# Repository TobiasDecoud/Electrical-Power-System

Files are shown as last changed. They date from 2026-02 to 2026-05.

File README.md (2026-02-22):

# Electrical-Power-Subsystem

Necesitamos:
 
  Potencia Requerida: Estimar el consumo de energía promedio y pico de todos los subsistemas del satélite.
  
  Órbita del Satélite: Determinar los períodos de luz solar y eclipse para dimensionar los paneles solares y la capacidad de las baterías.
  
  Vida Útil: Seleccionar componentes que puedan soportar la duración de la misión y los ciclos de carga y descarga.

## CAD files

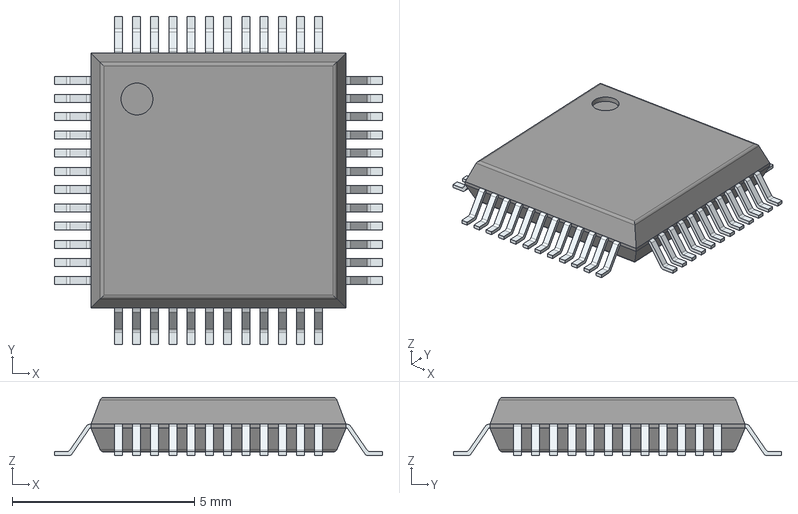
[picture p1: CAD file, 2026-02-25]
PCB/Footprints/LIB_STM32F103C8T6/STM32F103C8T6/3D/STM32F103C8T6.stp
9.00 x 9.00 x 1.60 mm
PinsArrayLR
PinsArrayTB

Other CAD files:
PCB/Footprints/LIB_STM32F103C8T6/STM32F103C8T6/Allegro/qfp50p900x900x160-48n.psm
PCB/Footprints/LIB_STM32F103C8T6/STM32F103C8T6/DEHDL/stm32f103c8t6/chips/chips.prt

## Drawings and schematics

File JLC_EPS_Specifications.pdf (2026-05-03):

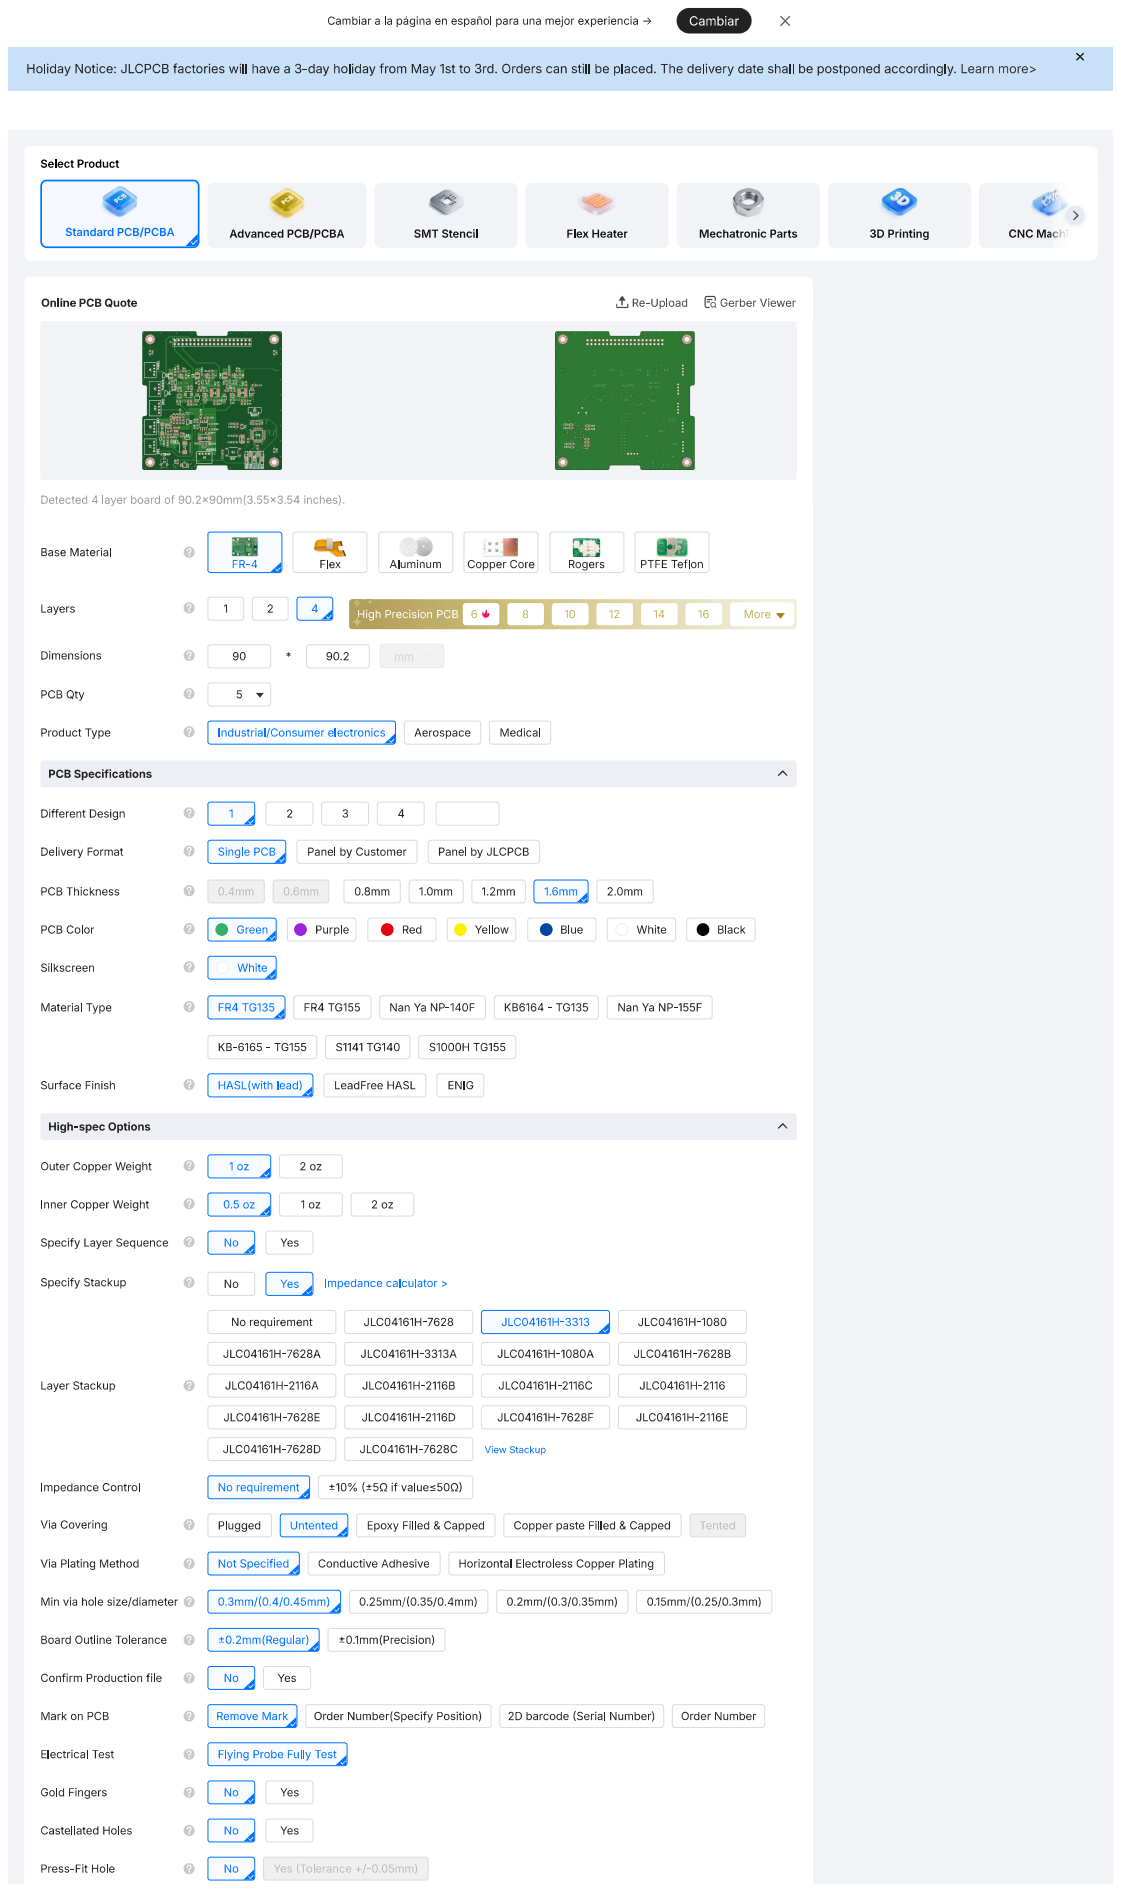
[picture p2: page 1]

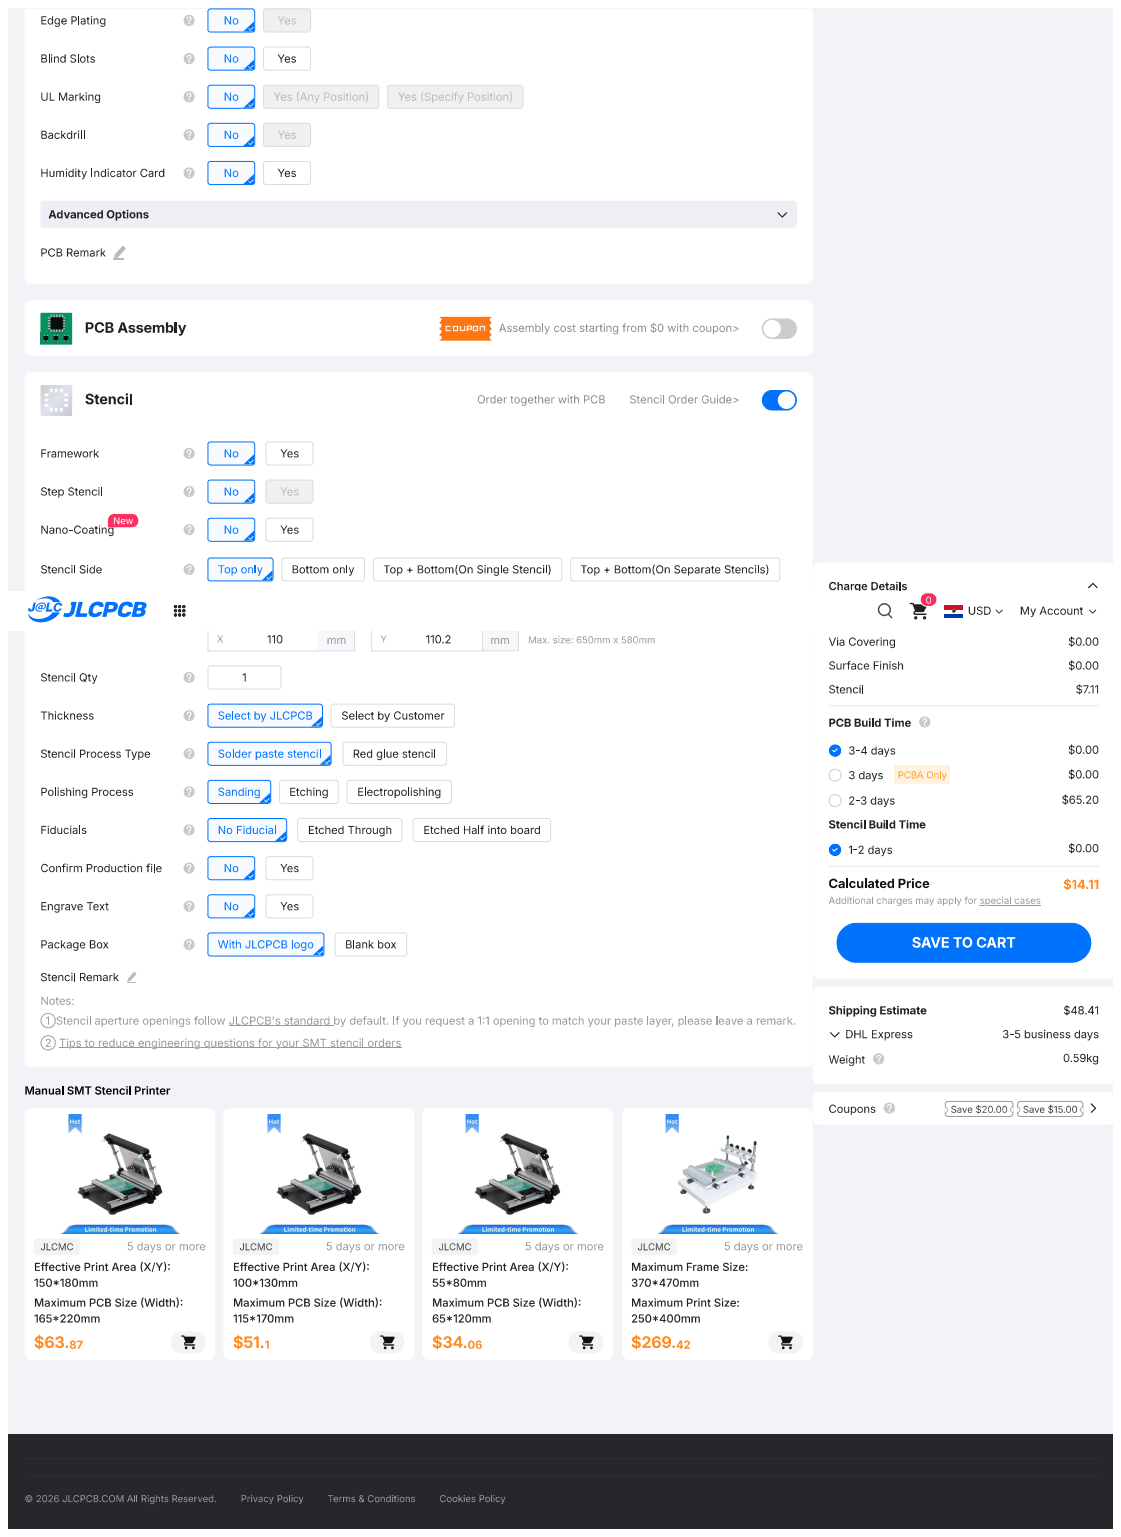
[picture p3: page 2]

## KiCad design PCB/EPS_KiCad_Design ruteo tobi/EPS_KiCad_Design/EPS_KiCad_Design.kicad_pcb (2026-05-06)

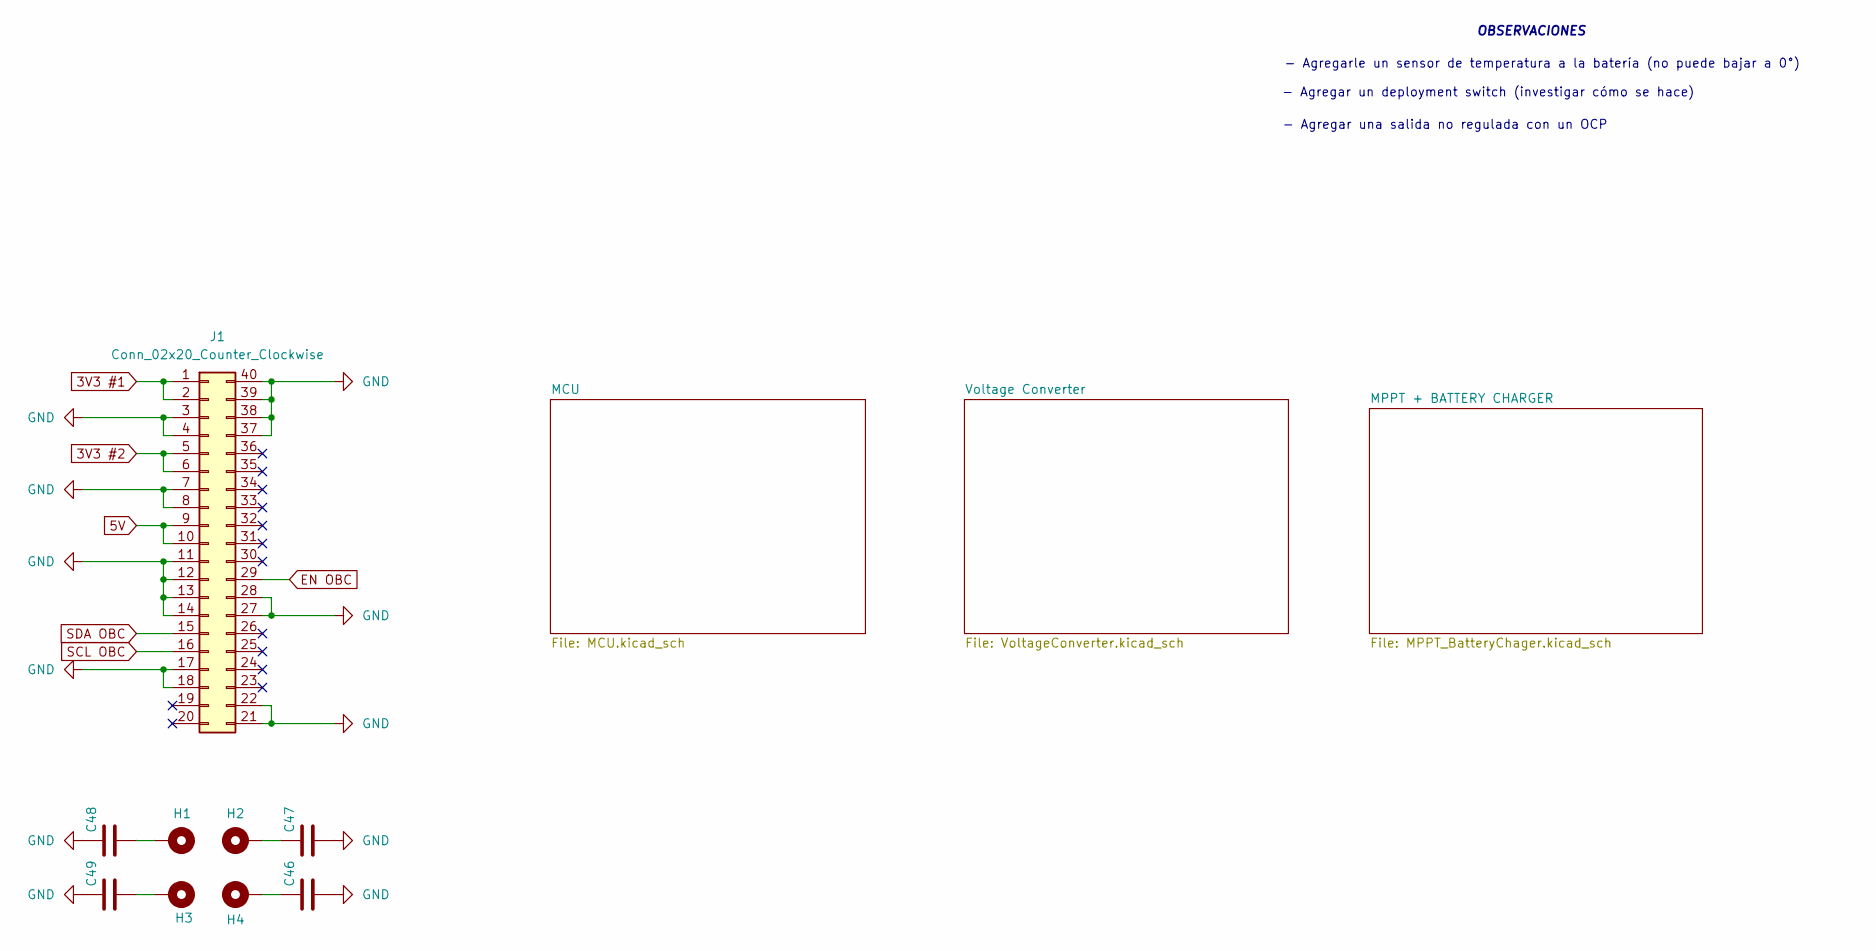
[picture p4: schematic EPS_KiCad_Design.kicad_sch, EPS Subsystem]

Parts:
C46, C47, C48, C49: 100nF; C_0805_2012Metric_Pad1.18x1.45mm_HandSolder
H1, H2, H3, H4: MountingHole_Pad; MountingHole_3.2mm_M3_Pad_Via
J1: Conn_02x20_Counter_Clockwise; PinSocket_2x20_P2.54mm_Vertical

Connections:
3V3 #1: J1.1, J1.2; also elsewhere on the board
3V3 #2: J1.5, J1.6; also elsewhere on the board
5V: J1.9, J1.10; also elsewhere on the board
EN OBC: J1.29; also elsewhere on the board
GND: C46.2, C47.2, C48.1, C49.1, J1.3, J1.4, J1.7, J1.8, J1.11, J1.12, J1.13, J1.14, J1.17, J1.18, J1.21, J1.22, J1.27, J1.28, J1.37, J1.38, J1.39, J1.40; also elsewhere on the board
unnamed: C46.1, H4.1
unnamed: C47.1, H2.1
unnamed: C48.2, H1.1
unnamed: C49.2, H3.1
SCL OBC: J1.16; also elsewhere on the board
SDA OBC: J1.15; also elsewhere on the board

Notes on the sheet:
OBSERVACIONES
- Agregar un deployment switch (investigar cómo se hace)
- Agregarle un sensor de temperatura a la batería (no puede bajar a 0°)
- Agregar una salida no regulada con un OCP

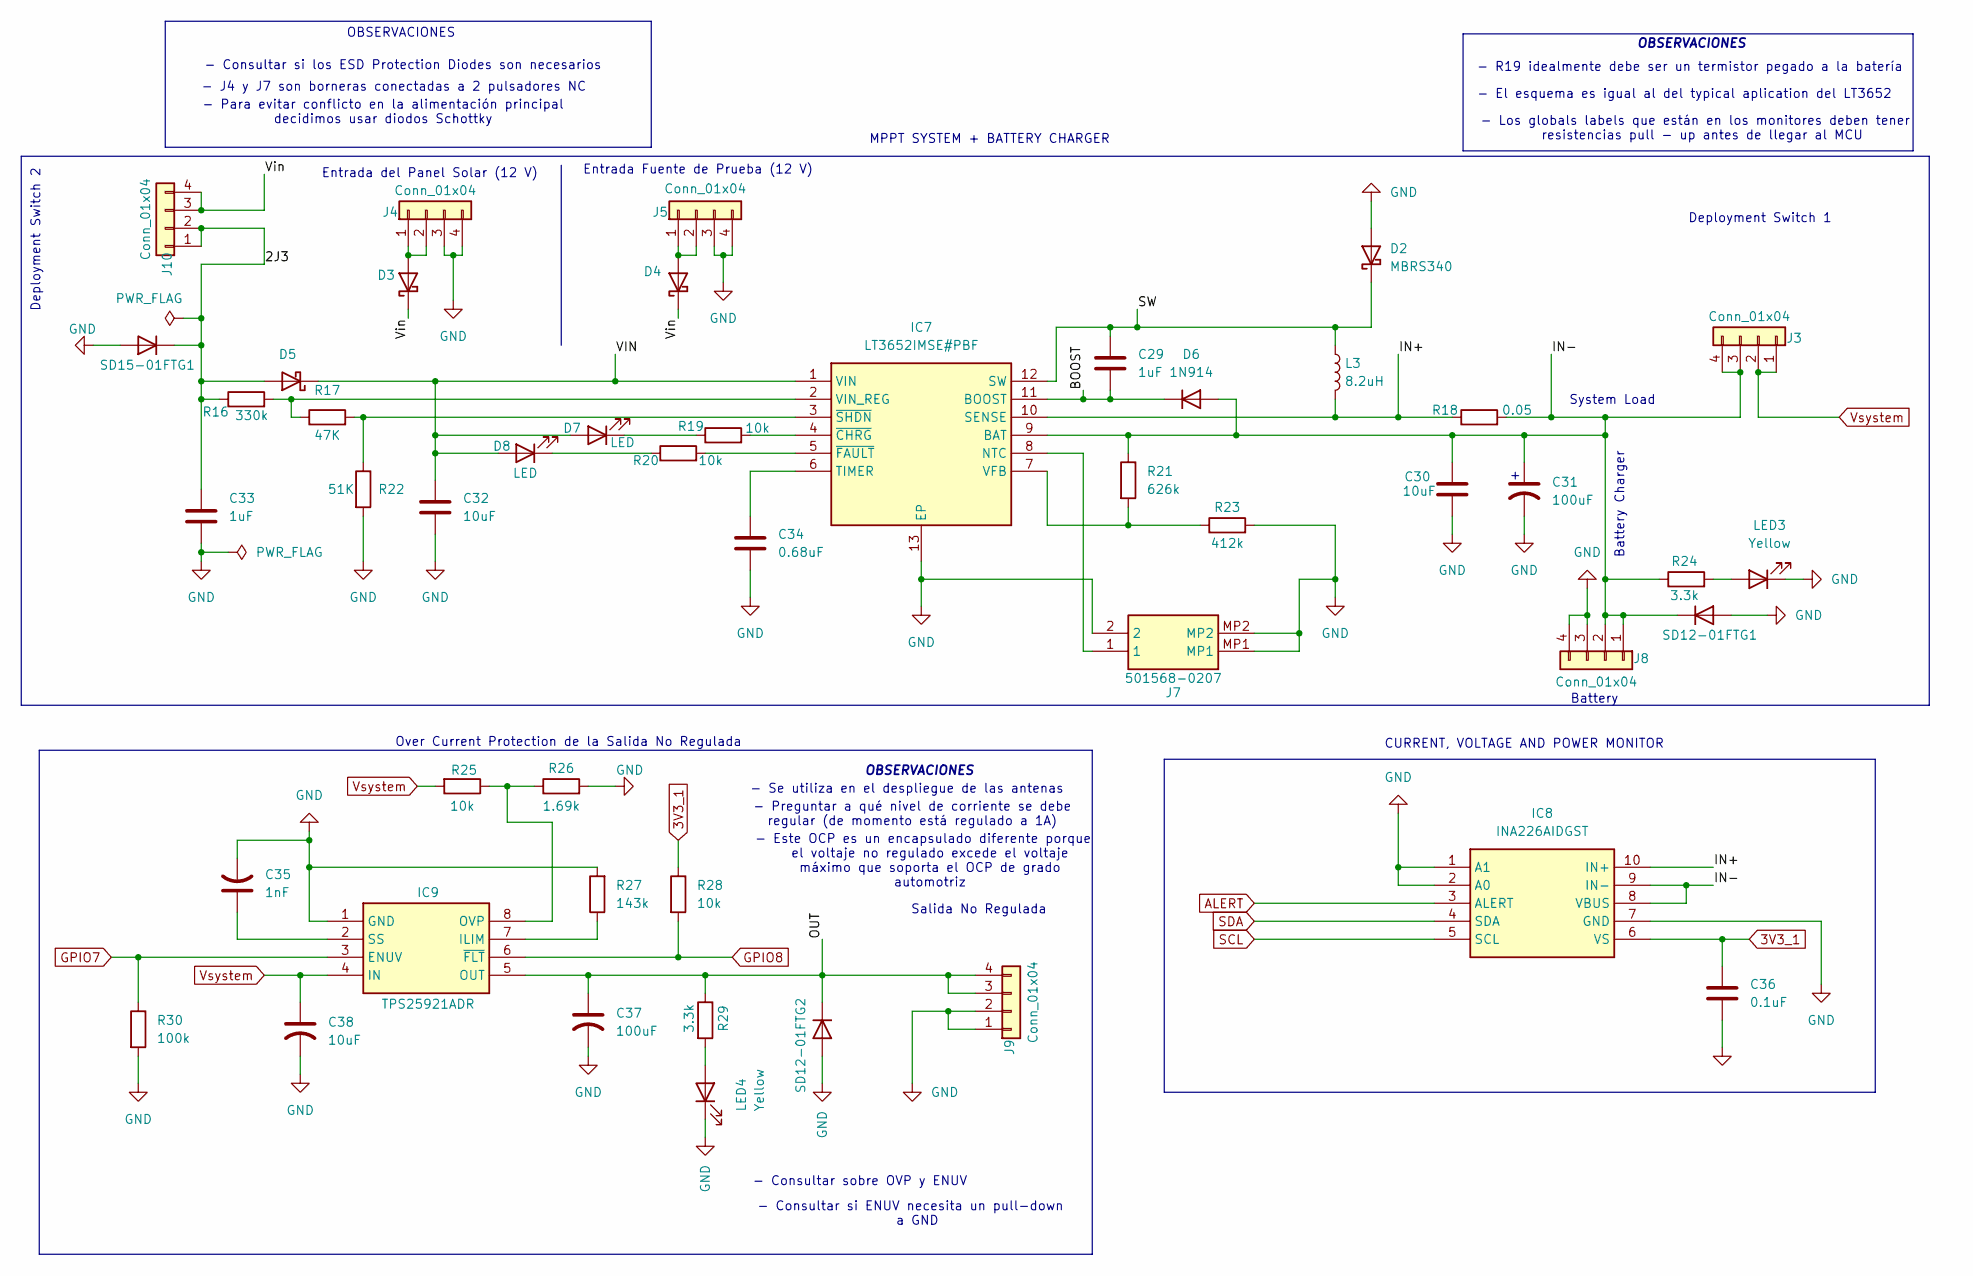
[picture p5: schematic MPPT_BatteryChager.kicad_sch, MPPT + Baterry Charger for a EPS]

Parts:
C29, C33: 1uF; C_0805_2012Metric_Pad1.18x1.45mm_HandSolder
C30, C32, C38: 10uF; C_0805_2012Metric_Pad1.18x1.45mm_HandSolder
C31, C37: 100uF; CAPPM7344X310N
C34: 0.68uF; C_0805_2012Metric_Pad1.18x1.45mm_HandSolder
C35: 1nF; C_0805_2012Metric_Pad1.18x1.45mm_HandSolder
C36: 0.1uF; C_0805_2012Metric_Pad1.18x1.45mm_HandSolder
D2, D3, D4, D5: MBRS340; SODFL3517X110N
D6: 1N914; SODFL4725X110N
D7, D8: LED; LED_0805_2012Metric_Pad1.15x1.40mm_HandSolder
IC7: LT3652IMSE#PBF; SOP65P490X110-13N; Mouser Part Number 584-LT3652IMSE#PBF
IC8: INA226AIDGST; SOP50P490X110-10N; Mouser Part Number 595-INA226AIDGST
IC9: TPS25921ADR; SOIC127P600X175-8N; Mouser Part Number 595-TPS25921ADR
J3, J4, J5, J8, J9, J10: Conn_01x04; 62000411722
J7: 501568-0207; 5015680207; Mouser Part Number 538-501568-0207
L3: 8.2uH; INDPM7168X300N
LED3, LED4: Yellow; LED_0805_2012Metric_Pad1.15x1.40mm_HandSolder
R16: 330k; R_0805_2012Metric_Pad1.20x1.40mm_HandSolder
R17: 47K; R_0805_2012Metric_Pad1.20x1.40mm_HandSolder
R18: 0.05; R_0805_2012Metric_Pad1.20x1.40mm_HandSolder
R19, R20, R25, R28: 10k; R_0805_2012Metric_Pad1.20x1.40mm_HandSolder
R21: 626k; R_0805_2012Metric_Pad1.20x1.40mm_HandSolder
R22: 51K; R_0805_2012Metric_Pad1.20x1.40mm_HandSolder
R23: 412k; R_0805_2012Metric_Pad1.20x1.40mm_HandSolder
R24, R29: 3.3k; R_0805_2012Metric_Pad1.20x1.40mm_HandSolder
R26: 1.69k; R_0805_2012Metric_Pad1.20x1.40mm_HandSolder
R27: 143k; R_0805_2012Metric_Pad1.20x1.40mm_HandSolder
R30: 100k; R_0805_2012Metric_Pad1.20x1.40mm_HandSolder
SD12-01FTG1, SD12-01FTG2: SOD2613X114N
SD15-01FTG1: D; SOD2613X114N

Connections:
3V3_1: C36.1, IC8.6 (VS), R28.1; also elsewhere on the board
/MPPT + BATTERY CHARGER/2J3: C33.1, D5.2 (A), J10.1, J10.2, R16.1, SD15-01FTG1.1 (K)
/MPPT + BATTERY CHARGER/BOOST: C29.2, D6.1 (K), IC7.11 (BOOST)
/MPPT + BATTERY CHARGER/IN+: IC7.10 (SENSE), IC8.10 (IN+), L3.2, R18.1
/MPPT + BATTERY CHARGER/IN-: C30.1, C31.1, D6.2 (A), IC7.9 (BAT), IC8.8 (VBUS), IC8.9 (IN-), J3.3, J3.4, J8.1, J8.2, R18.2, R21.1, R24.1, SD12-01FTG1.1 (K)
/MPPT + BATTERY CHARGER/OUT: C37.1, IC9.5 (OUT), J9.3, J9.4, R29.1, SD12-01FTG2.1 (K)
/MPPT + BATTERY CHARGER/SW: C29.1, D2.1 (K), IC7.12 (SW), L3.1
/MPPT + BATTERY CHARGER/VIN: C32.1, D5.1 (K), D7.2 (A), D8.2 (A), IC7.1 (VIN)
/MPPT + BATTERY CHARGER/Vin: D3.1 (K), D4.1 (K), J10.3, J10.4
ALERT: IC8.3 (ALERT); also elsewhere on the board
GND: C30.2, C31.2, C32.2, C33.2, C34.2, C35.2, C36.2, C37.2, C38.2, D2.2 (A), IC7.13 (EP), IC8.1 (A1), IC8.2 (A0), IC8.7 (GND), IC9.1 (GND), J4.3, J4.4, J5.3, J5.4, J7.2, J7.MP1, J7.MP2, J8.3, J8.4, J9.1, J9.2, LED3.1 (K), LED4.1 (K), R22.2, R23.2, R26.2, R27.2, R30.2, SD12-01FTG1.2 (A), SD12-01FTG2.2 (A), SD15-01FTG1.2 (A); also elsewhere on the board
GPIO7: IC9.3 (ENUV), R30.1; also elsewhere on the board
GPIO8: IC9.6 (~FLT), R28.2; also elsewhere on the board
unnamed: D3.2 (A), J4.1, J4.2
unnamed: D4.2 (A), J5.1, J5.2
unnamed: D7.1 (K), R19.1
unnamed: D8.1 (K), R20.1
unnamed: IC7.8 (NTC), J7.1
unnamed: C34.1, IC7.6 (TIMER)
unnamed: IC7.7 (VFB), R21.2, R23.1
unnamed: IC7.2 (VIN_REG), R16.2, R17.1
unnamed: IC7.4 (~CHRG), R19.2
unnamed: IC7.5 (~FAULT), R20.2
unnamed: IC7.3 (~SHDN), R17.2, R22.1
unnamed: IC9.7 (ILIM), R27.1
unnamed: IC9.8 (OVP), R25.1, R26.1
unnamed: C35.1, IC9.2 (SS)
unnamed: LED3.2 (A), R24.2
unnamed: LED4.2 (A), R29.2
SCL: IC8.5 (SCL); also elsewhere on the board
SDA: IC8.4 (SDA); also elsewhere on the board
Vsystem: C38.1, IC9.4 (IN), J3.1, J3.2, R25.2; also elsewhere on the board

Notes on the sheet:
CURRENT, VOLTAGE AND POWER MONITOR
- Se utiliza en el despliegue de las antenas
System Load
OBSERVACIONES
Entrada del Panel Solar (12 V)
- Los globals labels que están en los monitores deben tener resistencias pull - up antes de llegar al MCU
- Para evitar conflicto en la alimentación principal decidimos usar diodos Schottky
Battery Charger
- Este OCP es un encapsulado diferente porque el voltaje no regulado excede el voltaje máximo que soporta el OCP de grado automotriz
- El esquema es igual al del typical aplication del LT3652
Over Current Protection de la Salida No Regulada
- Consultar si ENUV necesita un pull-down a GND
Deployment Switch 1
Entrada Fuente de Prueba (12 V)
Deployment Switch 2
- R19 idealmente debe ser un termistor pegado a la batería
- J4 y J7 son borneras conectadas a 2 pulsadores NC
- Consultar si los ESD Protection Diodes son necesarios
- Consultar sobre OVP y ENUV
Salida No Regulada
- Preguntar a qué nivel de corriente se debe regular (de momento está regulado a 1A)
Battery
MPPT SYSTEM + BATTERY CHARGER

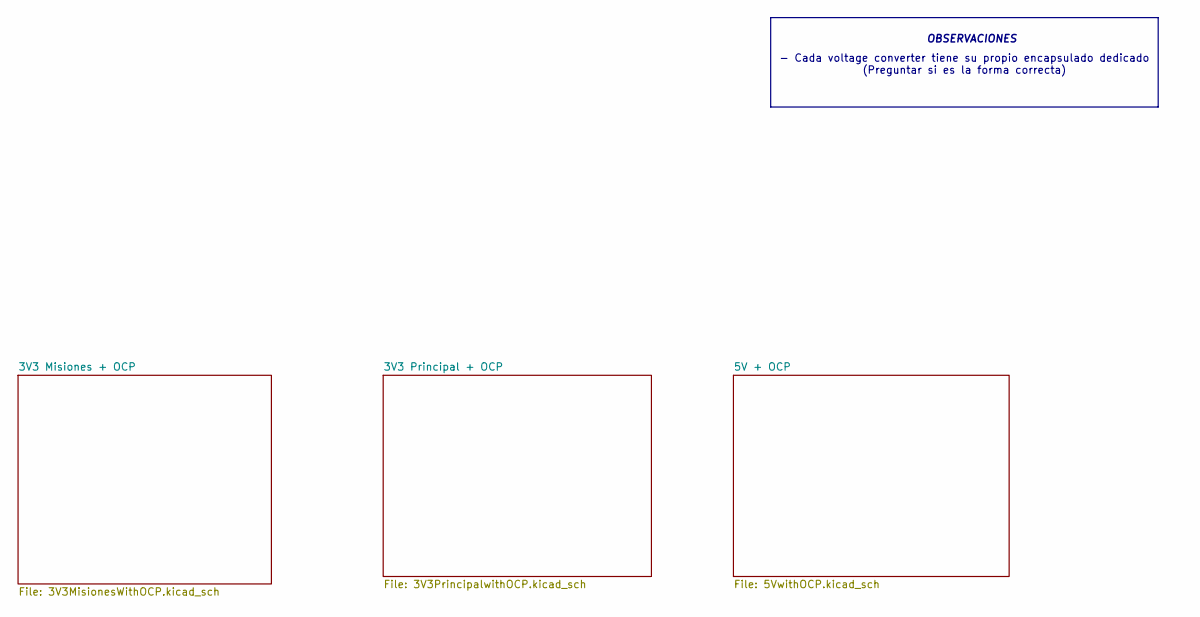
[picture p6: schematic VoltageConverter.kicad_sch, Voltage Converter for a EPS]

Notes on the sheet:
- Cada voltage converter tiene su propio encapsulado dedicado (Preguntar si es la forma correcta)
OBSERVACIONES

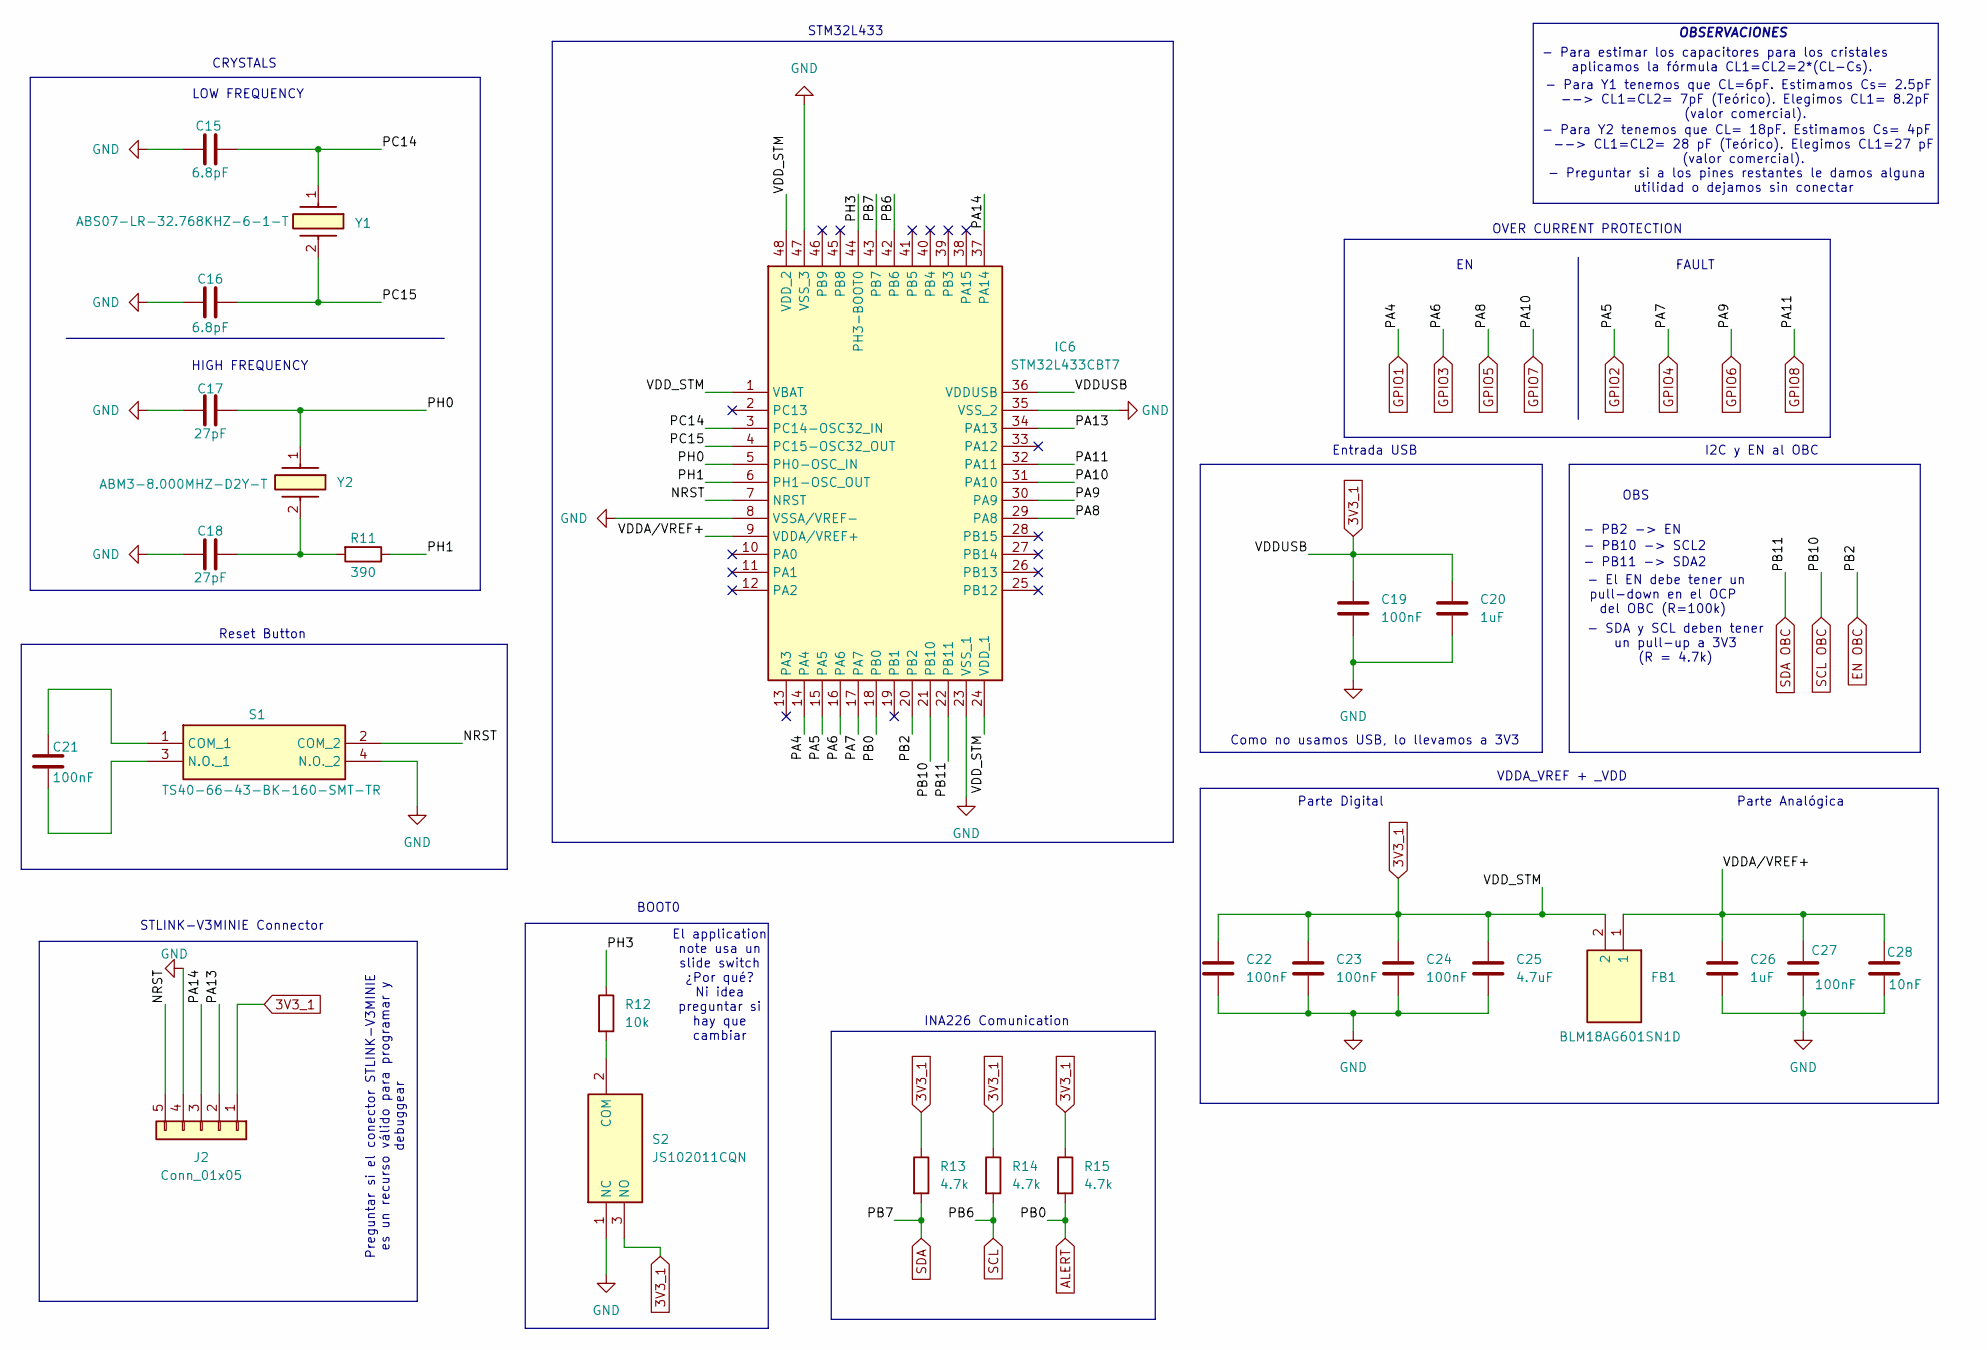
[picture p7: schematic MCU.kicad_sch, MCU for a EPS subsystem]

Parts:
C15, C16: 6.8pF; C_0805_2012Metric_Pad1.18x1.45mm_HandSolder
C17, C18: 27pF; C_0805_2012Metric_Pad1.18x1.45mm_HandSolder
C19, C21, C22, C23, C24, C27: 100nF; C_0805_2012Metric_Pad1.18x1.45mm_HandSolder
C20, C26: 1uF; C_0805_2012Metric_Pad1.18x1.45mm_HandSolder
C25: 4.7uF; C_0805_2012Metric_Pad1.18x1.45mm_HandSolder
C28: 10nF; C_0805_2012Metric_Pad1.18x1.45mm_HandSolder
FB1: BLM18AG601SN1D; BLM18SP221SN1B; Mouser Part Number 81-BLM11A601S
IC6: STM32L433CBT7; QFP50P900X900X160-48N; Mouser Part Number 511-STM32L433CBT7
J2: Conn_01x05; TSM10501LSV
R11: 390; R_0805_2012Metric_Pad1.20x1.40mm_HandSolder
R12: 10k; R_0805_2012Metric_Pad1.20x1.40mm_HandSolder
R13, R14, R15: 4.7k; R_0805_2012Metric_Pad1.20x1.40mm_HandSolder
S1: TS40-66-43-BK-160-SMT-TR; TS406643BK160SMTTR; Manufacturer_Part_Number TS40-66-43-BK-160-SMT-TR
S2: JS102011CQN; Mouser Part Number 611-JS102011CQN
Y1: ABS07-LR-32.768KHZ-6-1-T; ABS07LR32768kHz61T; Mouser Part Number 815-ABS07LR32.76-61T
Y2: ABM3-8.000MHZ-D2Y-T; ABM3; Mouser Part Number 815-ABM3-8-D2Y-T

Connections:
3V3_1: C19.1, C20.1, C22.1, C23.1, C24.1, C25.1, FB1.2, IC6.1 (VBAT), IC6.24 (VDD_1), IC6.36 (VDDUSB), IC6.48 (VDD_2), J2.1, R13.1, R14.1, R15.1, S2.3 (NO); also elsewhere on the board
/MCU/NRST: IC6.7 (NRST), J2.5, S1.2 (COM_2)
/MCU/PA13: IC6.34 (PA13), J2.2
/MCU/PA14: IC6.37 (PA14), J2.3
/MCU/PC14: C15.2, IC6.3 (PC14-OSC32_IN), Y1.1
/MCU/PC15: C16.2, IC6.4 (PC15-OSC32_OUT), Y1.2
/MCU/PH0: C17.1, IC6.5 (PH0-OSC_IN), Y2.1
/MCU/PH1: IC6.6 (PH1-OSC_OUT), R11.1
/MCU/PH3: IC6.44 (PH3-BOOT0), R12.1
/MCU/VDDA/VREF+: C26.1, C27.1, C28.1, FB1.1, IC6.9 (VDDA/VREF+)
ALERT: IC6.18 (PB0), R15.2; also elsewhere on the board
EN OBC: IC6.20 (PB2); also elsewhere on the board
GND: C15.1, C16.1, C17.2, C18.2, C19.2, C20.2, C22.2, C23.2, C24.2, C25.2, C26.2, C27.2, C28.2, IC6.8 (VSSA/VREF-), IC6.23 (VSS_1), IC6.35 (VSS_2), IC6.47 (VSS_3), J2.4, S1.4 (N.O._2), S2.1 (NC); also elsewhere on the board
GPIO1: IC6.14 (PA4); also elsewhere on the board
GPIO2: IC6.15 (PA5); also elsewhere on the board
GPIO3: IC6.16 (PA6); also elsewhere on the board
GPIO4: IC6.17 (PA7); also elsewhere on the board
GPIO5: IC6.29 (PA8); also elsewhere on the board
GPIO6: IC6.30 (PA9); also elsewhere on the board
GPIO7: IC6.31 (PA10); also elsewhere on the board
GPIO8: IC6.32 (PA11); also elsewhere on the board
unnamed: C18.1, R11.2, Y2.2
unnamed: C21.1, S1.1 (COM_1)
unnamed: C21.2, S1.3 (N.O._1)
unnamed: R12.2, S2.2 (COM)
SCL: IC6.42 (PB6), R14.2; also elsewhere on the board
SCL OBC: IC6.21 (PB10); also elsewhere on the board
SDA: IC6.43 (PB7), R13.2; also elsewhere on the board
SDA OBC: IC6.22 (PB11); also elsewhere on the board

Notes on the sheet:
BOOT0
- SDA y SCL deben tener un pull-up a 3V3 (R = 4.7k)
OBSERVACIONES
LOW FREQUENCY
- PB2 -> EN
- PB10 -> SCL2
OVER CURRENT PROTECTION
- El EN debe tener un pull-down en el OCP del OBC (R=100k)
Entrada USB
- Para Y2 tenemos que CL= 18pF. Estimamos Cs= 4pF --> CL1=CL2= 28 pF (Teórico). Elegimos CL1=27 pF (valor comercial).
- PB11 -> SDA2
INA226 Comunication
- Preguntar si a los pines restantes le damos alguna utilidad o dejamos sin conectar
Parte Digital
Preguntar si el conector STLINK-V3MINIE es un recurso válido para programar y debuggear
STLINK-V3MINIE Connector
OBS
Reset Button
I2C y EN al OBC
Parte Analógica
FAULT
Como no usamos USB, lo llevamos a 3V3
VDDA_VREF + _VDD
- Para Y1 tenemos que CL=6pF. Estimamos Cs= 2.5pF --> CL1=CL2= 7pF (Teórico). Elegimos CL1= 8.2pF (valor comercial).
El application note usa un slide switch ¿Por qué? Ni idea preguntar si hay que cambiar
CRYSTALS
HIGH FREQUENCY
STM32L433
- Para estimar los capacitores para los cristales aplicamos la fórmula CL1=CL2=2*(CL-Cs).

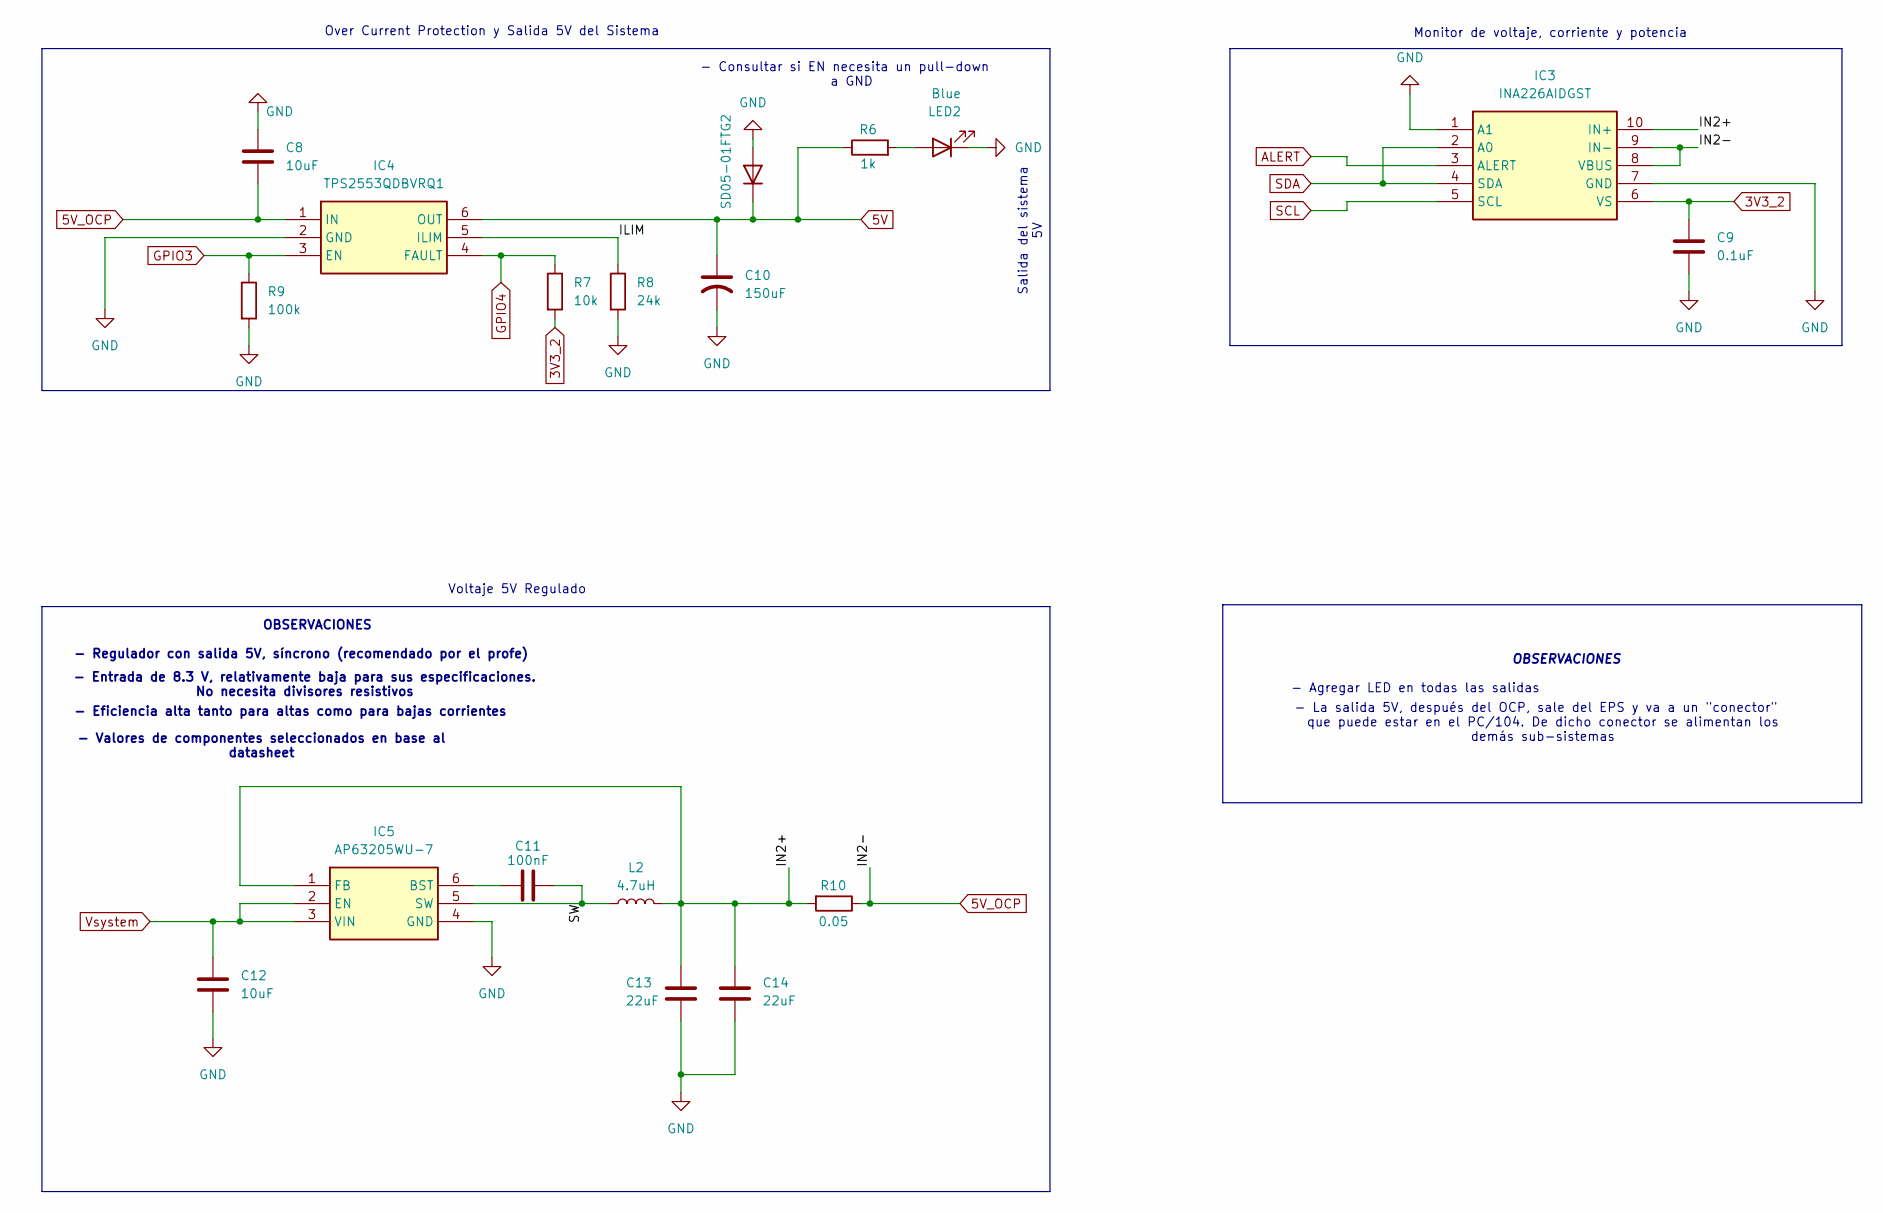
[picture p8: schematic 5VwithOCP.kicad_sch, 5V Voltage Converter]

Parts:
C8, C12: 10uF; C_0805_2012Metric_Pad1.18x1.45mm_HandSolder
C9: 0.1uF; C_0805_2012Metric_Pad1.18x1.45mm_HandSolder
C10: 150uF; CAPPM3528X210N
C11: 100nF; C_0805_2012Metric_Pad1.18x1.45mm_HandSolder
C13, C14: 22uF; C_0805_2012Metric_Pad1.18x1.45mm_HandSolder
IC3: INA226AIDGST; SOP50P490X110-10N; Mouser Part Number 595-INA226AIDGST
IC4: TPS2553QDBVRQ1; SOT95P280X145-6N; Mouser Part Number 595-TPS2553QDBVRQ1
IC5: AP63205WU-7; AP63205WU7; Mouser Part Number 621-AP63205WU-7
L2: 4.7uH; INDPM4441X200N
LED2: Blue; LED_0805_2012Metric_Pad1.15x1.40mm_HandSolder
R6: 1k; R_0805_2012Metric_Pad1.20x1.40mm_HandSolder
R7: 10k; R_0805_2012Metric_Pad1.20x1.40mm_HandSolder
R8: 24k; R_0805_2012Metric_Pad1.20x1.40mm_HandSolder
R9: 100k; R_0805_2012Metric_Pad1.20x1.40mm_HandSolder
R10: 0.05; R_0805_2012Metric_Pad1.20x1.40mm_HandSolder
SD05-01FTG2: D; SODFL3718X140N

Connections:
3V3_2: C9.1, IC3.6 (VS), R7.2; also elsewhere on the board
5V: C10.1, IC4.6 (OUT), R6.1, SD05-01FTG2.1 (K); also elsewhere on the board
5V_OCP: C8.2, IC3.8 (VBUS), IC3.9 (IN-), IC4.1 (IN), R10.1
/Voltage Converter/5V + OCP/ILIM: IC4.5 (ILIM), R8.1
/Voltage Converter/5V + OCP/IN2+: C13.1, C14.1, IC3.10 (IN+), IC5.1 (FB), L2.2, R10.2
/Voltage Converter/5V + OCP/SW: C11.2, IC5.5 (SW), L2.1
ALERT: IC3.3 (ALERT); also elsewhere on the board
GND: C8.1, C9.2, C10.2, C12.2, C13.2, C14.2, IC3.1 (A1), IC3.7 (GND), IC4.2 (GND), IC5.4 (GND), LED2.1 (K), R8.2, R9.2, SD05-01FTG2.2 (A); also elsewhere on the board
GPIO3: IC4.3 (EN), R9.1; also elsewhere on the board
GPIO4: IC4.4 (FAULT), R7.1; also elsewhere on the board
unnamed: C11.1, IC5.6 (BST)
unnamed: LED2.2 (A), R6.2
SCL: IC3.5 (SCL); also elsewhere on the board
SDA: IC3.2 (A0), IC3.4 (SDA); also elsewhere on the board
Vsystem: C12.1, IC5.2 (EN), IC5.3 (VIN); also elsewhere on the board

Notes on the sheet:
- Consultar si EN necesita un pull-down a GND
Voltaje 5V Regulado
OBSERVACIONES
- Eficiencia alta tanto para altas como para bajas corrientes
- Agregar LED en todas las salidas
- Entrada de 8.3 V, relativamente baja para sus especificaciones. No necesita divisores resistivos
Salida del sistema 5V
- La salida 5V, después del OCP, sale del EPS y va a un "conector" que puede estar en el PC/104. De dicho conector se alimentan los demás sub-sistemas
- Valores de componentes seleccionados en base al datasheet
Over Current Protection y Salida 5V del Sistema
Monitor de voltaje, corriente y potencia
- Regulador con salida 5V, síncrono (recomendado por el profe)

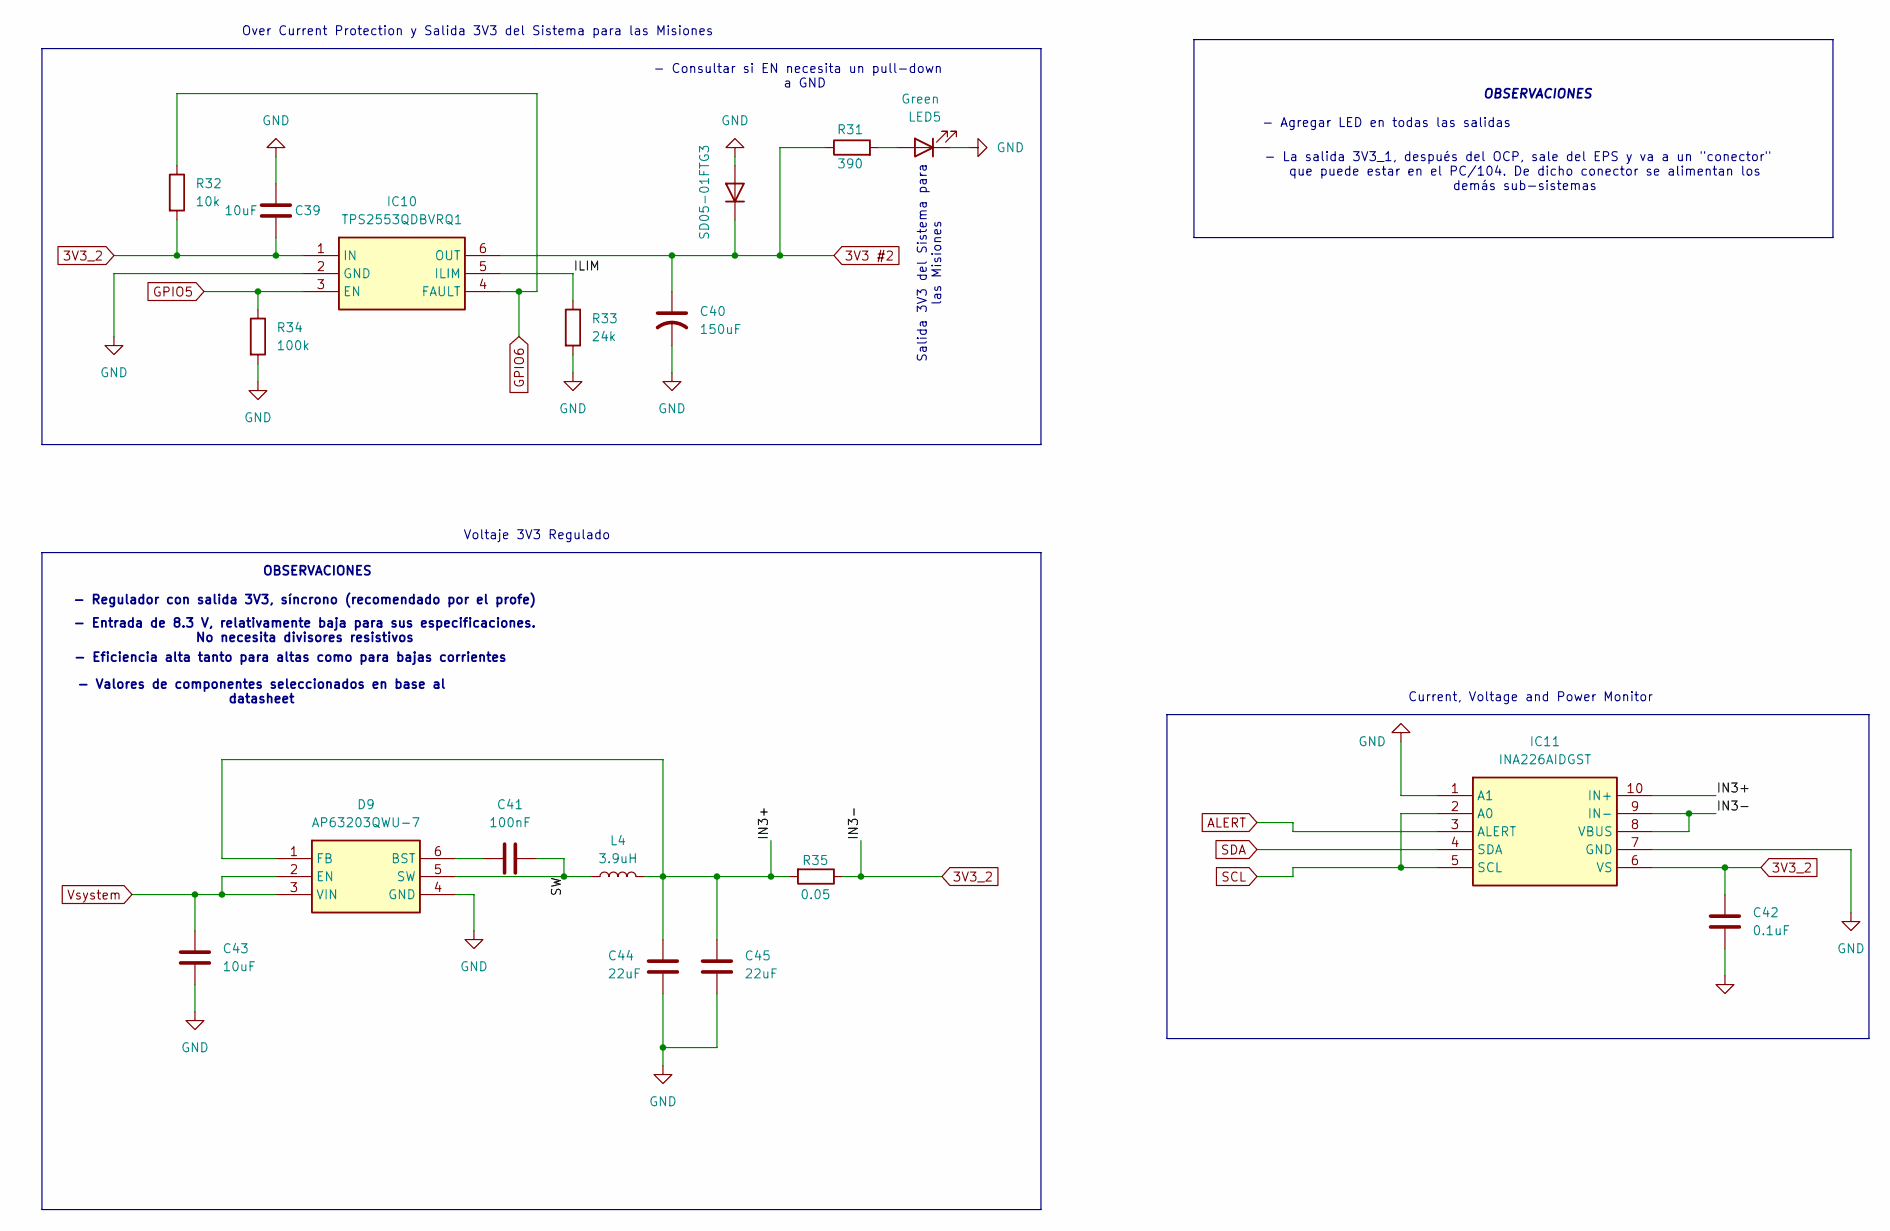
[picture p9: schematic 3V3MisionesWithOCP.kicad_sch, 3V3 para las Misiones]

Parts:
C39, C43: 10uF; C_0805_2012Metric_Pad1.18x1.45mm_HandSolder
C40: 150uF; CAPPM3528X210N
C41: 100nF; C_0805_2012Metric_Pad1.18x1.45mm_HandSolder
C42: 0.1uF; C_0805_2012Metric_Pad1.18x1.45mm_HandSolder
C44, C45: 22uF; C_0805_2012Metric_Pad1.18x1.45mm_HandSolder
D9: AP63203QWU-7; SOT95P280X100-6N; Mouser Part Number 621-AP63203QWU-7
IC10: TPS2553QDBVRQ1; SOT95P280X145-6N; Mouser Part Number 595-TPS2553QDBVRQ1
IC11: INA226AIDGST; SOP50P490X110-10N; Mouser Part Number 595-INA226AIDGST
L4: 3.9uH; ASPI0628150MT1
LED5: Green; LED_0805_2012Metric_Pad1.15x1.40mm_HandSolder
R31: 390; R_0805_2012Metric_Pad1.20x1.40mm_HandSolder
R32: 10k; R_0805_2012Metric_Pad1.20x1.40mm_HandSolder
R33: 24k; R_0805_2012Metric_Pad1.20x1.40mm_HandSolder
R34: 100k; R_0805_2012Metric_Pad1.20x1.40mm_HandSolder
R35: 0.05; R_0805_2012Metric_Pad1.20x1.40mm_HandSolder
SD05-01FTG3: D; SOD2613X114N

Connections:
3V3 #2: C40.1, IC10.6 (OUT), R31.1, SD05-01FTG3.1 (K); also elsewhere on the board
3V3_2: C39.1, C42.1, IC10.1 (IN), IC11.6 (VS), IC11.8 (VBUS), IC11.9 (IN-), R32.2, R35.1; also elsewhere on the board
/Voltage Converter/3V3 Misiones + OCP/ILIM: IC10.5 (ILIM), R33.1
/Voltage Converter/3V3 Misiones + OCP/IN3+: C44.1, C45.1, D9.1 (FB), IC11.10 (IN+), L4.2, R35.2
/Voltage Converter/3V3 Misiones + OCP/SW: C41.2, D9.5 (SW), L4.1
ALERT: IC11.3 (ALERT); also elsewhere on the board
GND: C39.2, C40.2, C42.2, C43.2, C44.2, C45.2, D9.4 (GND), IC10.2 (GND), IC11.1 (A1), IC11.7 (GND), LED5.1 (K), R33.2, R34.2, SD05-01FTG3.2 (A); also elsewhere on the board
GPIO5: IC10.3 (EN), R34.1; also elsewhere on the board
GPIO6: IC10.4 (FAULT), R32.1; also elsewhere on the board
unnamed: C41.1, D9.6 (BST)
unnamed: LED5.2 (A), R31.2
SCL: IC11.2 (A0), IC11.5 (SCL); also elsewhere on the board
SDA: IC11.4 (SDA); also elsewhere on the board
Vsystem: C43.1, D9.2 (EN), D9.3 (VIN); also elsewhere on the board

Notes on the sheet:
OBSERVACIONES
- Eficiencia alta tanto para altas como para bajas corrientes
- Entrada de 8.3 V, relativamente baja para sus especificaciones. No necesita divisores resistivos
Voltaje 3V3 Regulado
- Regulador con salida 3V3, síncrono (recomendado por el profe)
- Agregar LED en todas las salidas
Current, Voltage and Power Monitor
- Valores de componentes seleccionados en base al datasheet
Salida 3V3 del Sistema para las Misiones
- Consultar si EN necesita un pull-down a GND
Over Current Protection y Salida 3V3 del Sistema para las Misiones
- La salida 3V3_1, después del OCP, sale del EPS y va a un "conector" que puede estar en el PC/104. De dicho conector se alimentan los demás sub-sistemas

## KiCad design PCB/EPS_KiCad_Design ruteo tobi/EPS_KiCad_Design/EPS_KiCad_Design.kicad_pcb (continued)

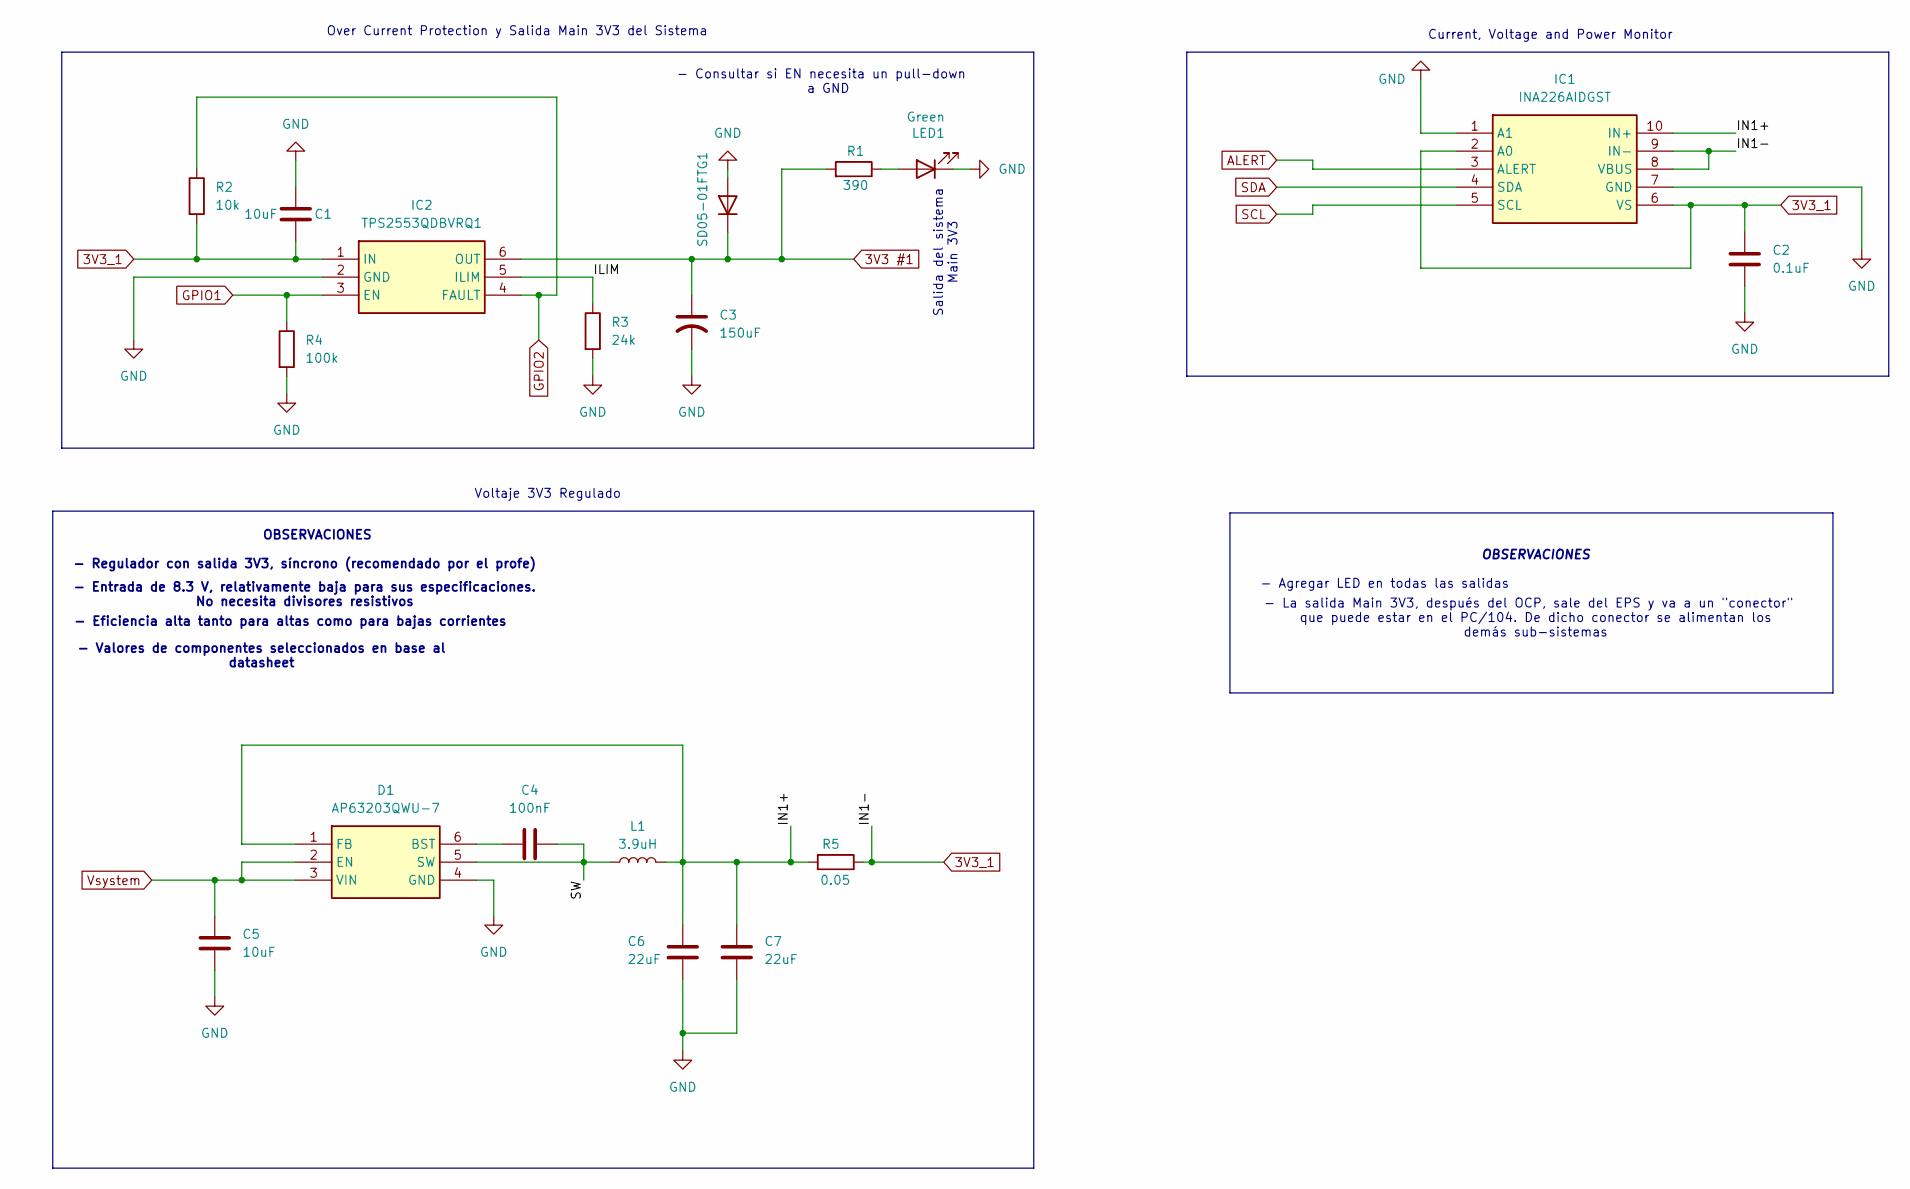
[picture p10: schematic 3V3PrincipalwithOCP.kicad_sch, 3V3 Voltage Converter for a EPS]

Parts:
C1, C5: 10uF; C_0805_2012Metric_Pad1.18x1.45mm_HandSolder
C2: 0.1uF; C_0805_2012Metric_Pad1.18x1.45mm_HandSolder
C3: 150uF; CAPPM3528X210N
C4: 100nF; C_0805_2012Metric_Pad1.18x1.45mm_HandSolder
C6, C7: 22uF; C_0805_2012Metric_Pad1.18x1.45mm_HandSolder
D1: AP63203QWU-7; SOT95P280X100-6N; Mouser Part Number 621-AP63203QWU-7
IC1: INA226AIDGST; SOP50P490X110-10N; Mouser Part Number 595-INA226AIDGST
IC2: TPS2553QDBVRQ1; SOT95P280X145-6N; Mouser Part Number 595-TPS2553QDBVRQ1
L1: 3.9uH; ASPI0628150MT1
LED1: Green; LED_0805_2012Metric_Pad1.15x1.40mm_HandSolder
R1: 390; R_0805_2012Metric_Pad1.20x1.40mm_HandSolder
R2: 10k; R_0805_2012Metric_Pad1.20x1.40mm_HandSolder
R3: 24k; R_0805_2012Metric_Pad1.20x1.40mm_HandSolder
R4: 100k; R_0805_2012Metric_Pad1.20x1.40mm_HandSolder
R5: 0.05; R_0805_2012Metric_Pad1.20x1.40mm_HandSolder
SD05-01FTG1: D; SOD2613X114N

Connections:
3V3 #1: C3.1, IC2.6 (OUT), R1.2, SD05-01FTG1.1 (K); also elsewhere on the board
3V3_1: C1.1, C2.1, IC1.2 (A0), IC1.6 (VS), IC1.8 (VBUS), IC1.9 (IN-), IC2.1 (IN), R2.2, R5.1; also elsewhere on the board
/Voltage Converter/3V3 Principal + OCP/ILIM: IC2.5 (ILIM), R3.1
/Voltage Converter/3V3 Principal + OCP/IN1+: C6.1, C7.1, D1.1 (FB), IC1.10 (IN+), L1.2, R5.2
/Voltage Converter/3V3 Principal + OCP/SW: C4.2, D1.5 (SW), L1.1
ALERT: IC1.3 (ALERT); also elsewhere on the board
GND: C1.2, C2.2, C3.2, C5.2, C6.2, C7.2, D1.4 (GND), IC1.1 (A1), IC1.7 (GND), IC2.2 (GND), LED1.1 (K), R3.2, R4.2, SD05-01FTG1.2 (A); also elsewhere on the board
GPIO1: IC2.3 (EN), R4.1; also elsewhere on the board
GPIO2: IC2.4 (FAULT), R2.1; also elsewhere on the board
unnamed: C4.1, D1.6 (BST)
unnamed: LED1.2 (A), R1.1
SCL: IC1.5 (SCL); also elsewhere on the board
SDA: IC1.4 (SDA); also elsewhere on the board
Vsystem: C5.1, D1.2 (EN), D1.3 (VIN); also elsewhere on the board

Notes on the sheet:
- Consultar si EN necesita un pull-down a GND
Voltaje 3V3 Regulado
Current, Voltage and Power Monitor
- Entrada de 8.3 V, relativamente baja para sus especificaciones. No necesita divisores resistivos
- Regulador con salida 3V3, síncrono (recomendado por el profe)
- Eficiencia alta tanto para altas como para bajas corrientes
OBSERVACIONES
- Valores de componentes seleccionados en base al datasheet
Salida del sistema Main 3V3
Over Current Protection y Salida Main 3V3 del Sistema
- Agregar LED en todas las salidas
- La salida Main 3V3, después del OCP, sale del EPS y va a un "conector" que puede estar en el PC/104. De dicho conector se alimentan los demás sub-sistemas

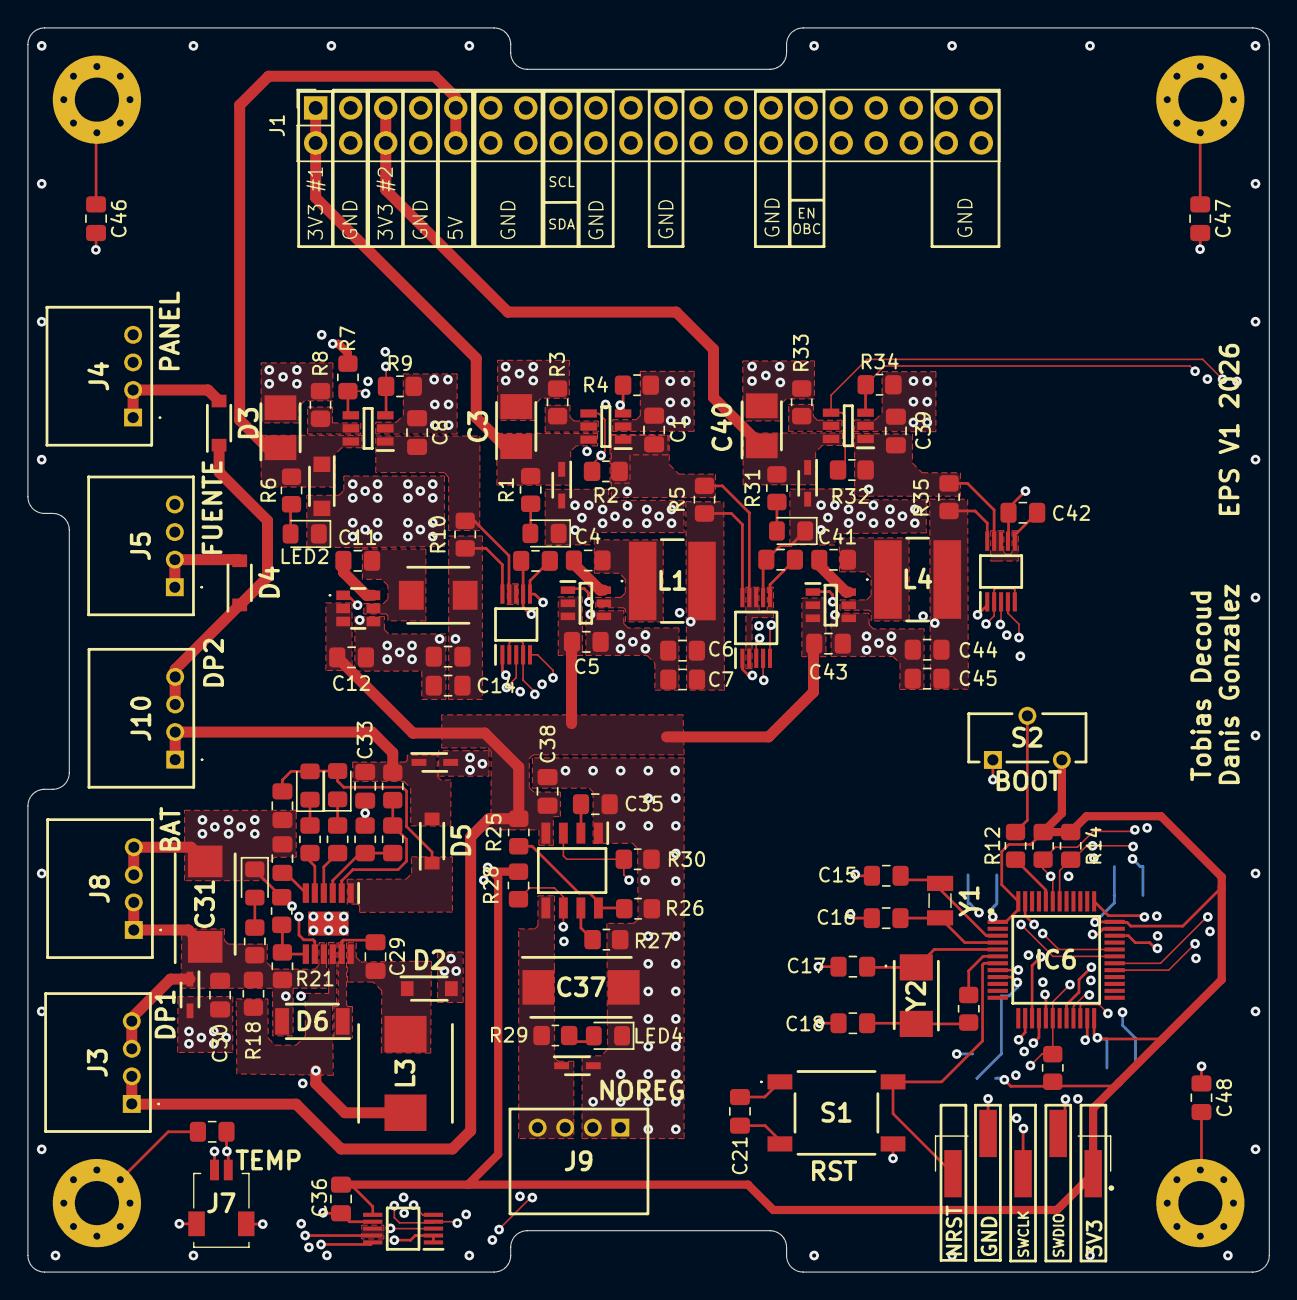
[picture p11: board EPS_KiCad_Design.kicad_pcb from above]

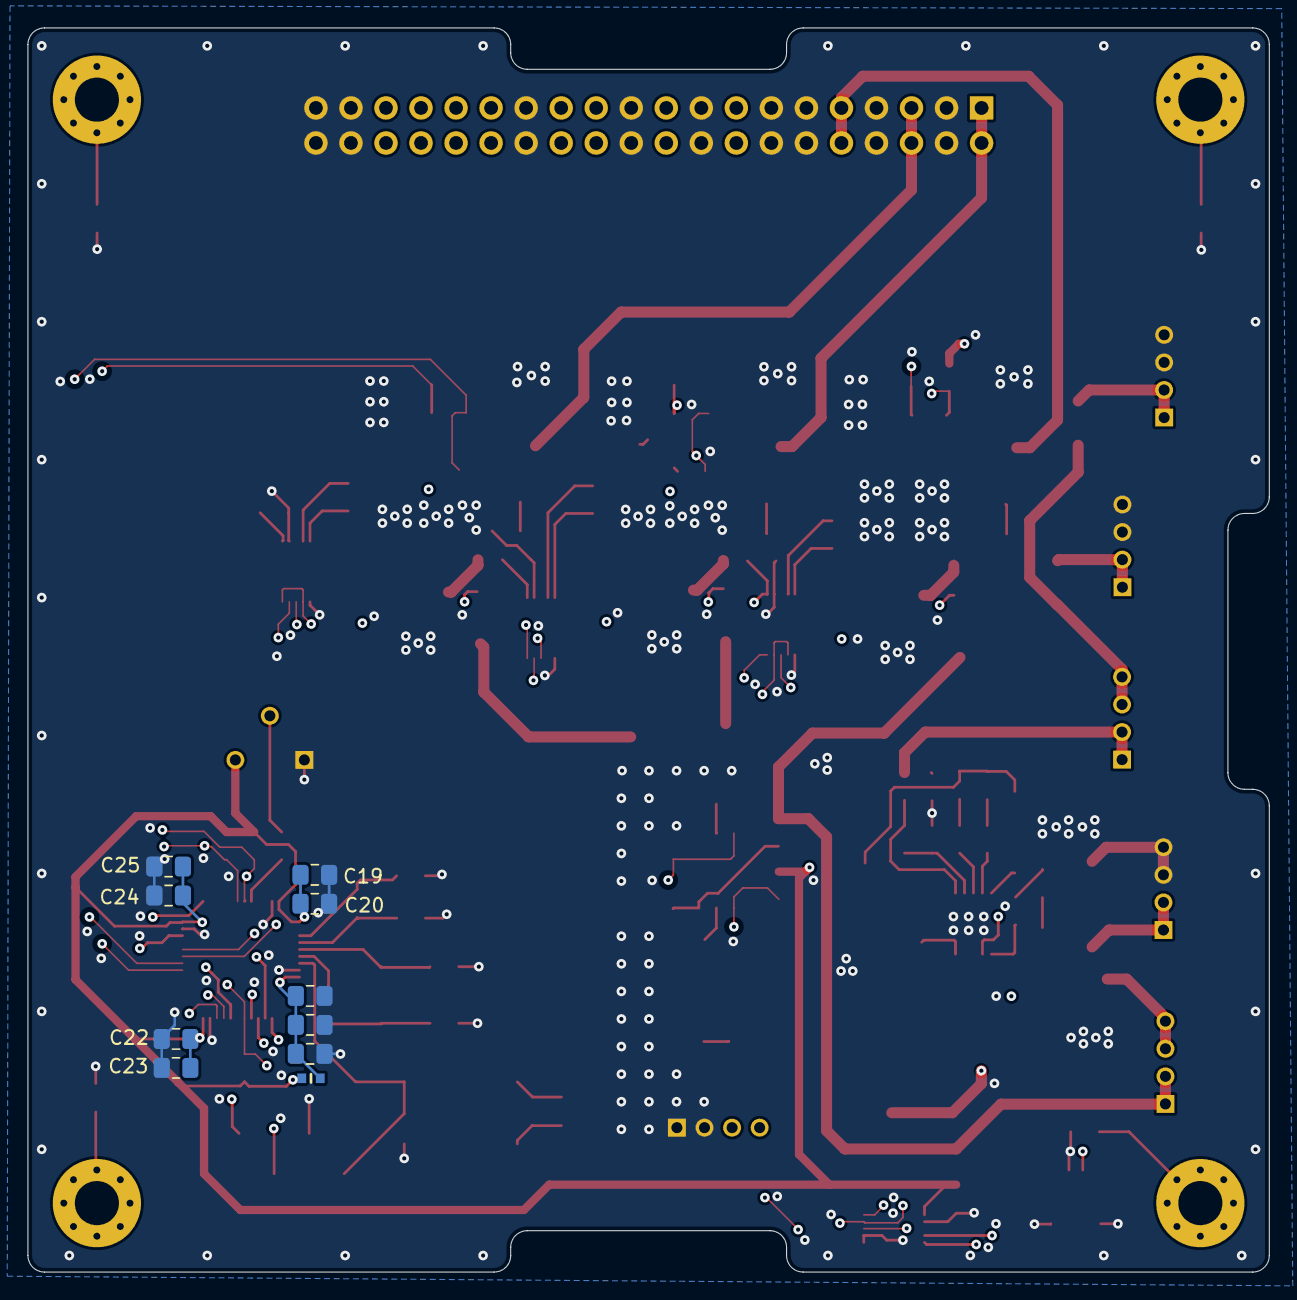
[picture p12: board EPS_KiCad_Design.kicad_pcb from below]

Board: 4 copper layers, 90.0 x 90.2 mm, 137 parts (10 on the bottom side), 78 nets.

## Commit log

2026-02-22 Actualizacion de README
2026-02-25 Inicio PCB
    [EDI2CAP.CFG, PCB_EPS.kicad_pcb, PCB_EPS.kicad_sch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]
2026-03-03 actualizacion pcb¨
2026-03-09 Main PCB - EPS
    [12V.kicad_sch, 3V3.kicad_sch, 5V.kicad_sch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]
2026-03-29 Cambio en el diagrama
2026-03-29 Cambie ubicacion de baterry en el diagrama
2026-04-15 Actualizacion del PCB en Kicad
    [12V.kicad_sch, 3V3.kicad_sch, 3V3MisionesWithOCP.kicad_sch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]
2026-04-20 cargue pcb
    [12V.kicad_sch, 3V3.kicad_sch, 3V3MisionesWithOCP.kicad_sch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]
2026-04-27 pcb tobi
    [3V3MisionesWithOCP.kicad_sch, 5VwithOCP.kicad_sch, EPS_KiCad_Design.kicad_pcb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]
2026-04-27 Ruteo parcial de MCU
    [EPS_KiCad_Design.kicad_pcb]
2026-04-28 Agregue cosas al ruteo MCU
    [EPS_KiCad_Design.kicad_pcb]
2026-04-28 Correcciones MCU ruteo
    [EPS_KiCad_Design.kicad_pcb]
2026-04-28 RUTEO MCU
    [EPS_KiCad_Design.kicad_pcb]
2026-04-28 Correccion de STP de los cristales
    [EPS_KiCad_Design.kicad_pcb]
2026-04-28 Cambios menores
    [EPS_KiCad_Design.kicad_pcb]
2026-04-29 Actualizacion del PCB
    [3V3MisionesWithOCP.kicad_sch, 3V3PrincipalwithOCP.kicad_sch, EPS_KiCad_Design.kicad_pcb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]
2026-04-30 Cambio de conector
    Conector header de 5 posiciones
    [MCU.kicad_sch]
2026-05-02 Estapadines agregados en el diseño
    [EPS_KiCad_Design.kicad_pcb]
2026-05-02 cambios en el ruteo
    [EPS_KiCad_Design.kicad_pcb, EPS_KiCad_Design.kicad_sch, MCU.kicad_sch]
2026-05-03 Cambios pcb
    [EPS_KiCad_Design-B_Cu.gbr, EPS_KiCad_Design-B_Mask.gbr, EPS_KiCad_Design-B_Paste.gbr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]
2026-05-03 cambios minimos para pasar el DFM Checker
    [EPS_KiCad_Design-B_Cu.gbr, EPS_KiCad_Design-B_Mask.gbr, EPS_KiCad_Design-B_Paste.gbr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]
2026-05-04 Agrege nombres visibles a PC104
    [EPS_KiCad_Design.kicad_pcb]
2026-05-04 anhadi el fabrication file
    [EPS_KiCad_Design-B_Cu.gbr, EPS_KiCad_Design-B_Mask.gbr, EPS_KiCad_Design-B_Paste.gbr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]
2026-05-06 Agregue nombres al pcb
    [EPS_KiCad_Design-B_Cu.gbr, EPS_KiCad_Design-B_Mask.gbr, EPS_KiCad_Design-B_Paste.gbr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]
2026-05-24 Diagrama de Flujo
